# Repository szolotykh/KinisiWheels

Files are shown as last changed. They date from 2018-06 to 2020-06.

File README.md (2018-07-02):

# KinisiWheels
Kinisi wheels are mecanum wheels for DIY projects, designed in mind to be easily made at home or in a small shop without any machinery or sophisticated tools. Wheels parts can be made on any 3D printer without any support material and using only popular types of filament.

## Links
* Facebook: https://www.facebook.com/vsreality
* Instagram: https://www.instagram.com/vsrealityrobotics
* YouTube: https://www.youtube.com/channel/UCnxfsZNEosBJmcfHZYKonFg

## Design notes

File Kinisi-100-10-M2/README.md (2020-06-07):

Kinisi Mecanum Wheels Model 2 (100 mm 10 rollers)
===

Kinisi wheels are mecanum wheels for DIY projects, designed in mind to be easily made at home or in a small shop without any machinery or sophisticated tools. Wheels parts can be made on any 3D printer without any support material and using only popular types of filament.

* Diameter of the wheel: 100mm
* Number of rollers: 10
* Bore diameter: 6mm
* One wheel constructs from 14 printed parts
* Screws assembly

Why this wheels was designe? Main goal is to make low cost and easy to make, available in different sizes and configurations mecanum wheels that can be use in DIY projects.

# Print Settings
* Resolution: Nozzle 0.4 mm, Layer 0.2 mm
* Infill: 30%
* Notes: Rollers should be printed with 50% Infill

# Materials and tools

## Materials
* PLA/ABS Red and Black
* TPU Black
* 3mm Steel Rod (3 feet per wheel) Low-Carbon Steel Rod: https://www.mcmaster.com/#8920K14, Carbon Steel Rod https://www.mcmaster.com/#5544T222
* Locknuts (28 per wheel) https://www.mcmaster.com/#90576A102
* Washers (20 per wheel) https://www.mcmaster.com/#90965A130
* Worm-Drive Clamps https://www.mcmaster.com/#5388K14

## Tools
* 3D Pronter
* Steel Hacksaw
* Die handles
* M3 die
* Thread cutting oil
* 5.5 Wrench
* Pliers
* File set
* Vise

# Filament Cost
| Part | Material | Color | Item weight, g | Amount | Total weight, g | Print time, min |
|---|---|---|---|---|---|---|
| Inner side | PLA | Red | 10.5 | 1 | 10.5 | 81 | 
| Outer side | PLA | Red | 10.5 | 1 | 10.5 | 81 | 
| Roller | TPU | Black | 4.5 | 10 | 45 | 320 | 
| Center | PLA | Red | 15 | 1 | 15 | 128 | 
| Hub | PLA | Black | 2 | 1 | 2 | 20 | 
| Total | | | | 14 | 83 | 10h 30m | 

Total cost of filament: $2.81
PLA $28 for 1kg
TPU $31 for 0.8kg

# Mounting Parts Cost
| Part | Cost | Amount | One wheel cost | 
|---|---|---|---|
| 3mm Steel Rod (3 feet) | 3.67 per three feet | 3 feet | 3.67 | 
| Locknuts | 3.36 per 100 | 28 | 0.94 | 
| Washers | 2.80 per 100 | 20 | 0.56 | 
| Worm-Drive Clamps | 6.02 per 10 | 1 | 0.6 | 
| Total | | | 5.77 | 

# Total cost 
Total cost for 1 wheel is about $8.58

# Roller axis and mounting screws
In order to make roller axis and mounting screws you need to prepare a 3 feet of low-carbon or carbon steel rod (see material section). Then, you should cut the rod on 10 pieces of length 60mm for roller axes, and 4 pieces of length 46 mm for mounting screws using any steel sow. Then, you should make a small chamfer on both ends of each axis and screws. Finally, make 4mm thread on each side of them using M3 die with die holder, remember to apply thread cutting oil before cutting thread.Watch videos below to see how thread cutting and assembling the wheel can be done.

# Videos
* Threading roller axis for Kinisi wheels https://www.youtube.com/watch?v=sRk97DvpTi4
* Assembling Kinisi Mecanum Wheel Model 2 https://www.youtube.com/watch?v=DggJK2FCUzg

# Social:
* Facebook: https://www.facebook.com/vsreality
* Instagram: https://www.instagram.com/vsrealityrobotics
* YouTube: https://www.youtube.com/channel/UCnxfsZNEosBJmcfHZYKonFg

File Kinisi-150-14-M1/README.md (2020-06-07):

Kinisi Mecanum Wheels Model 1 (150 mm 14 rollers)
===
Kinisi wheels is a pair of left and right mecanum wheels. Designed specially to be made on 3D printer with out any support structures.
* Diameter of the wheel: 150mm
* Number of rollers: 14
* Bore diameter: 8mm
* One wheel constructs from 37 printed parts
* Require ServoCity 8mm hub
* Screws assembles

# Print Settings
Rafts:Yes
Supports:No
Resolution: Nozzle 0.4 mm, Layer 0.2 mm
Infill:30%

You can printed all parts from PLA or ABS except roller tires which you should print from TPU other wise you will not be able to put a tire on a roller core.
There some statistic which I collected while 3d print wheels and parts count:

| Part | Material | Color | Item weight, g | Amount | Total weight, g | Time to print, min |  
|---|---|---|---|---|---|---|
| Inside | PLA | Red | 44 | 1 | 44 | 312 | 
| Outside | PLA | Red | 44 | 1 | 44 | 312 | 
| Roller core | PLA | Black | 1.93 | 14 | 27 | 300 | 
| Roller tire | TPU | Black | 6.86 | 14 | 96 | 625 | 
| Central support | PLA | Red | 10 | 1 | 10 | 69 | 
| Secondary beam  | PLA | Black | 3 | 6 | 18 | 136 | 
| Total | | | | 37 | 239 | 29h 14m | 

Total cost of filament: *$6.98*
* PLA $28 for 1kg
* TPU $31 for 0.8kg

Reaf is not require but preferable for roller cores, and  secondary beans.

# Parts (Screws and Nuts)
| Part | Amount | Total cost | McMaster ID |
|---|---|---|---|
| Screw, M4 65 mm | 14 | $3.99 | 91290A083 | 
| Locknut, M4 | 14 | $0.57 | 90576A103 | 
| Scrow, 6-32, 1-3/4 | 10 | $1.42 | 91251A158 | 
| Locknut, 6-32 | 10 | $0.28 | 90631A007 | 
| Total | | $6.26 | | 

Also you need 8mm bore hub from ServoCity
https://www.servocity.com/770-set-screw-hubs#348=105

# Assembling Kinisi Wheel
https://www.youtube.com/watch?v=snKVXKz8MpM

# Social:
* Facebook: https://www.facebook.com/vsreality
* Instagram: https://www.instagram.com/vsrealityrobotics

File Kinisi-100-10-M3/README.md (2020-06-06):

Kinisi Mecanum Wheels Model 3 (100 mm 10 rollers)
===

Kinisi wheels are mecanum wheels for DIY projects, designed in mind to be easily made at home or in a small shop without any machinery or sophisticated tools. Wheels parts can be made on any 3D printer without any support material and using only popular types of filament.

Diameter of the wheel: 100mm
Number of rollers: 10
Bore diameter: 6mm
One wheel constructs from 14 printed parts
Screws assembly
Why this wheels was designe?

Main goal is to make low cost and easy to make, available in different sizes and configurations mecanum wheels that can be use in DIY projects.
Access to the design

If you are interesting to modify design and give me some feedback how to improve it you can download the source from Autodesk gallery: https://gallery.autodesk.com/fusion360/projects/137421/kinisi-mecanum-wheels-model-3-100-mm-10-rollers

# Print Settings
* Rafts: No
* Supports: No
* Resolution: Nozzle 0.4 mm, Layer 0.2 mm
* Infill: 30%
* Notes: Rollers should be printed with 50% Infill

# Materials
* PLA/ABS Red and Black
* TPU Black
* 3mm Steel Rod (3 feet per wheel)
** Low-Carbon Steel Rod https://www.mcmaster.com/#8920K14
** Carbon Steel Rod https://www.mcmaster.com/#5544T222
* Locknuts (12 per wheel) https://www.mcmaster.com/#90576A102
* Washers (20 per wheel) https://www.mcmaster.com/#90965A130
* Worm-Drive Clamps https://www.mcmaster.com/#5388K14

# Tools
* 3D Pronter
* Steel Hacksaw
* Die handles
* M3 die
* Thread cutting oil
* 5.5 Wrench
* Pliers
* File set
* Vise

# Filament Cost
| Part | Material | Color | Item weight, g | Amount | Total weight, g | Print time, min |
|---|---|---|---|---|---|---|
| Inner side | PLA | Red | 11 | 1 | 11 | 91 | 
| Outer side | PLA | Red | 11 | 1 | 11 | 91 | 
| Roller | TPU | Black | 4.5 | 10 | 45 | 320 | 
| Center | PLA | Red | 15 | 1 | 15 | 128 | 
| Hub | PLA | Black | 3 | 1 | 3 | 20 | 
| Total | | | | 14 | 85 | 11h | 

Total cost of filament: $2.86
PLA $28 for 1kg
TPU $31 for 0.8kg

# Mounting Parts Cost
| Part | Cost | Amount | One wheel cost | 
|---|---|---|---|
| 3mm Steel Rod (3 feet) | 3.67 per three feet | 3 feet | 3.67 | 
| Locknuts | 3.36 per 100 | 12 | 0.4 | 
| Washers | 2.80 per 100 | 20 | 0.56 | 
| Worm-Drive Clamps | 6.02 per 10 | 1 | 0.6 | 
| Total | | | 5.23 | 

# Total cost
Total cost for 1 wheel is about $8.09

# Roller axis and mounting screws
In order to make roller axis and mounting screws you need to prepare a 3 feet of low-carbon or carbon steel rod (see material section). Then, you should cut the rod on 10 pieces of length 53.7 mm for roller axes, and 6 pieces of length 46 mm for mounting screws using any steel sow. Then, you should make a small chamfer on both ends of each axis and screws. Finally, make 4mm thread on each side of 46 mm rods using M3 die with die holder, remember to apply thread cutting oil before cutting thread. Watch videos below to see how thread cutting and assembling the wheel can be done.

# Assembling Kinisi Wheel Model 3
https://www.youtube.com/watch?v=xH2ZxzZyMjw

# Social
* Facebook: https://www.facebook.com/vsreality
* Instagram: https://www.instagram.com/vsrealityrobotics
* YouTube: https://www.youtube.com/channel/UCnxfsZNEosBJmcfHZYKonFg
* Autodesk: https://gallery.autodesk.com/fusion360/users/5C4LRV5ULQZH

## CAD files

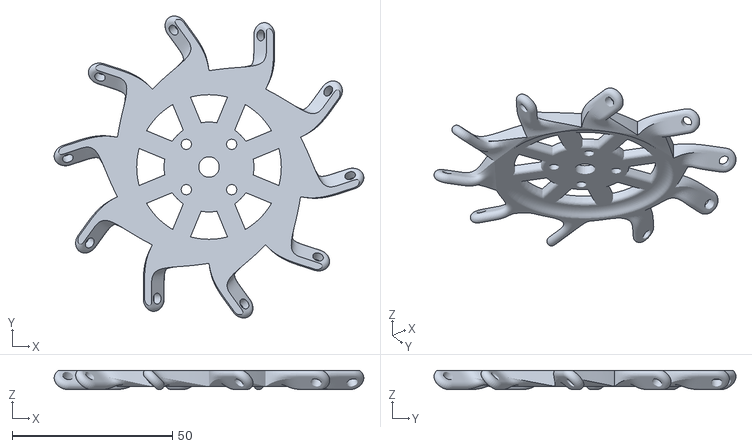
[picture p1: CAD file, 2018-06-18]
Kinisi-100-10-M2/Left outer side.stl
96.5 x 94.1 x 6.04

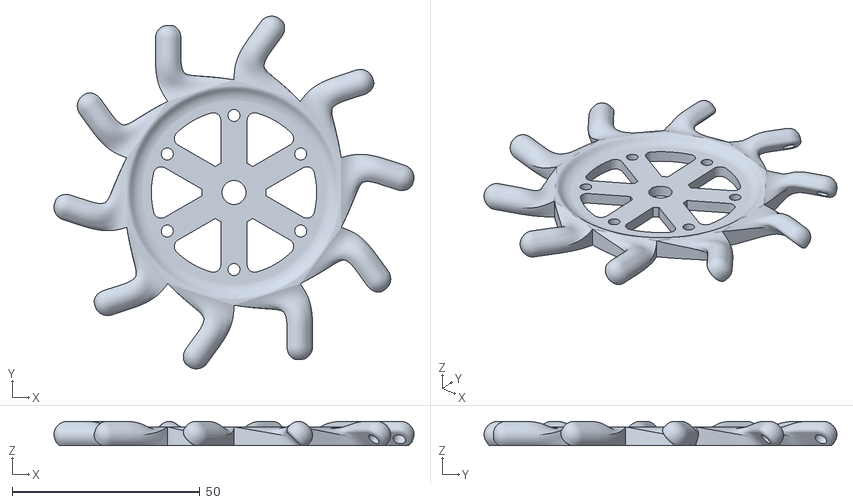
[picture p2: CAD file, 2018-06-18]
Kinisi-100-10-M3/Left inner side.stl
95.8 x 93.9 x 6.47

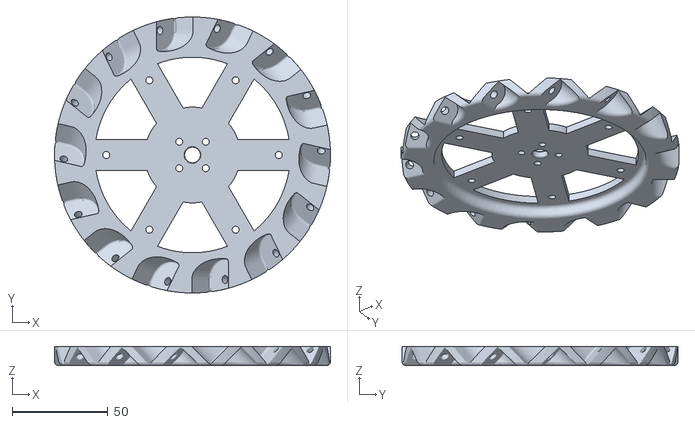
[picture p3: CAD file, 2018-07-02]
Kinisi-150-14-M1/Inside right.stl
144.0 x 144.0 x 10.0

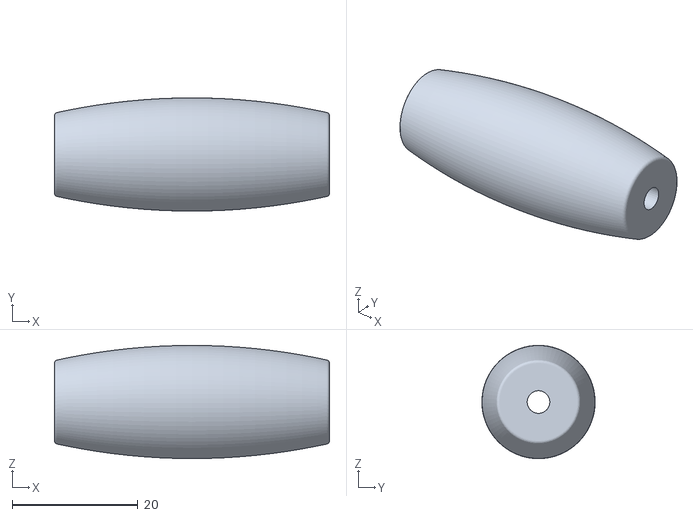
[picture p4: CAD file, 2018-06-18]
Kinisi-100-10-M2/Roller.stl
43.7 x 18.0 x 18.0

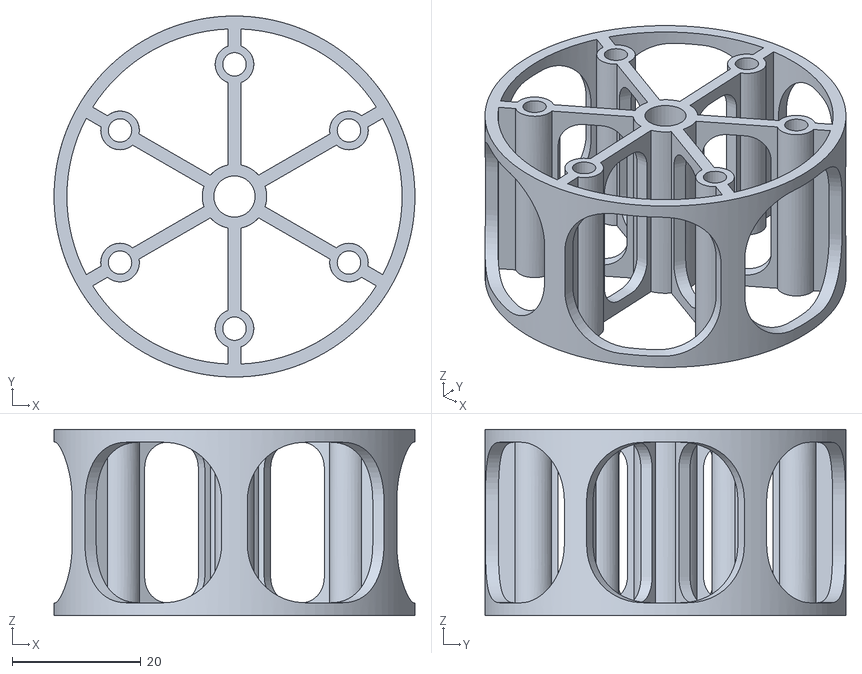
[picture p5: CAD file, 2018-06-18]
Kinisi-100-10-M3/Center.stl
56.0 x 56.0 x 28.9

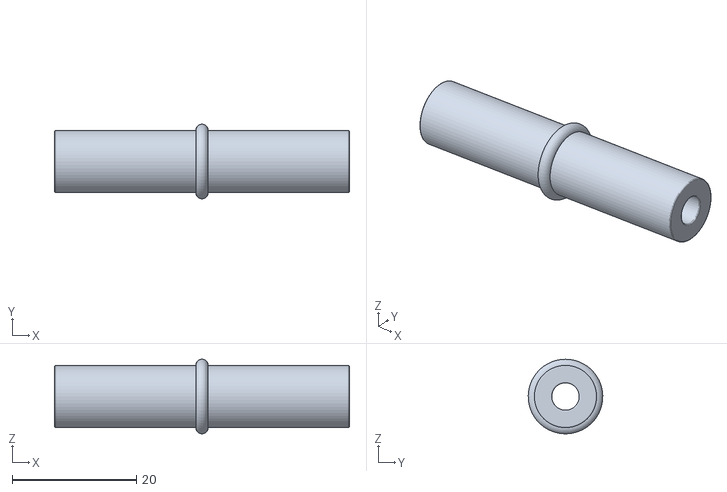
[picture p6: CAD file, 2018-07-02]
Kinisi-150-14-M1/Roller core.stl
47.4 x 12.0 x 12.0

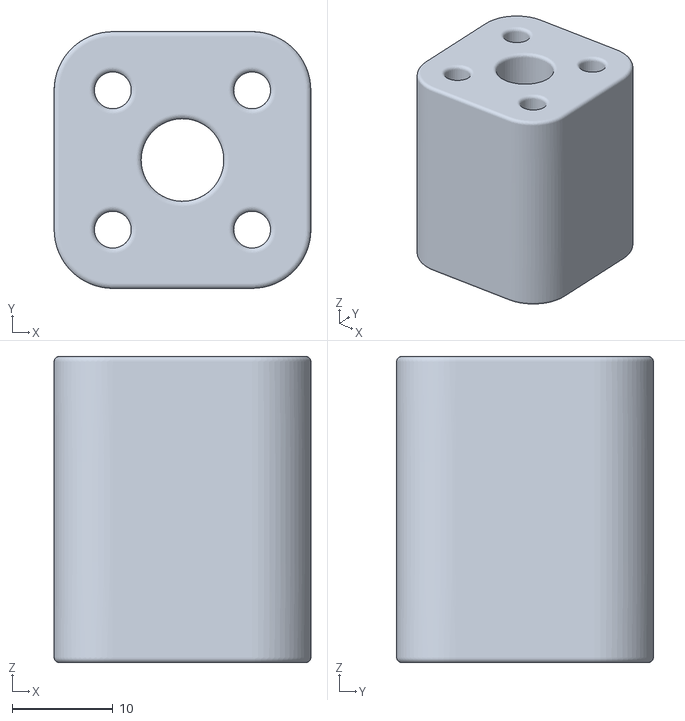
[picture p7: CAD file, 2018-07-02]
Kinisi-150-14-M1/Central support.stl
25.5 x 25.5 x 30.4

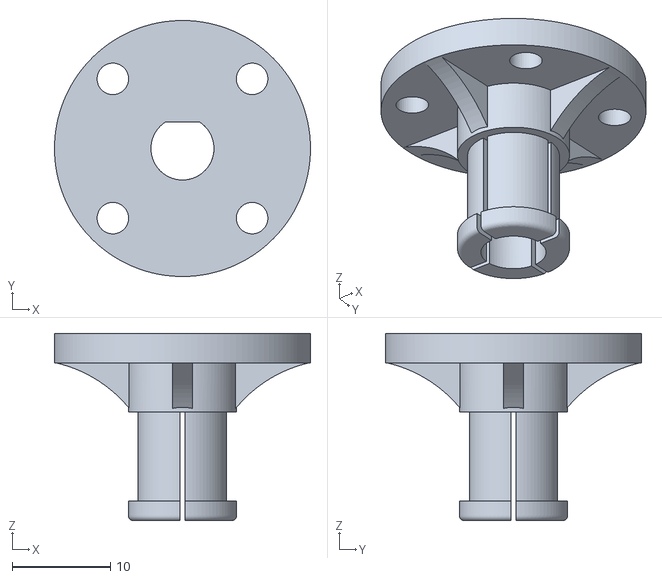
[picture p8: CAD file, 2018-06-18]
Kinisi-100-10-M2/Hub for motor.stl
26.0 x 26.0 x 19.0

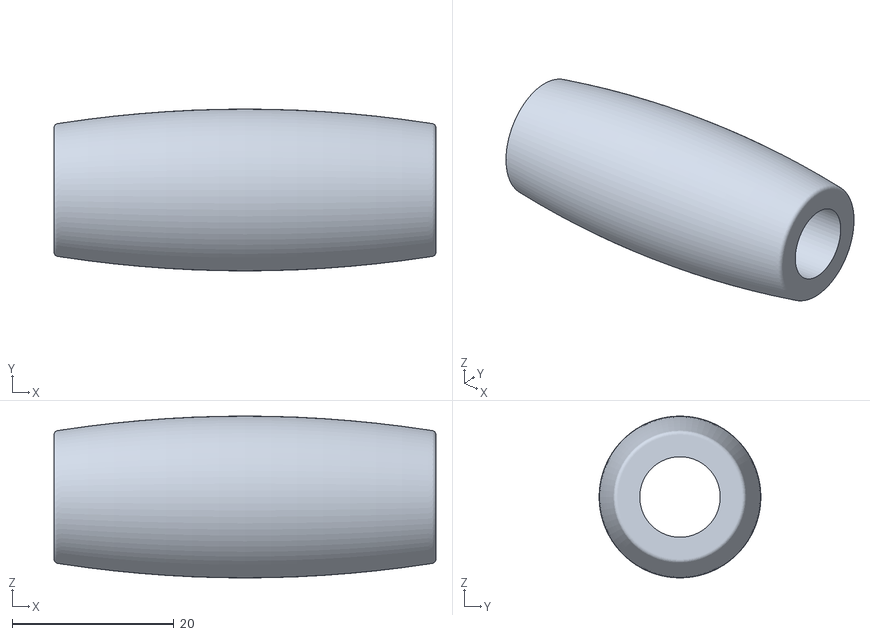
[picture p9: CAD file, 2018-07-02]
Kinisi-150-14-M1/Roller tire.stl
47.2 x 20.0 x 20.0

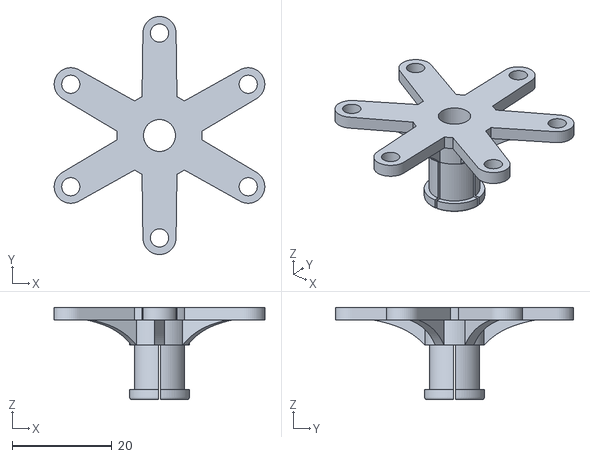
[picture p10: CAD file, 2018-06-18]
Kinisi-100-10-M3/Hub.stl
42.1 x 47.6 x 18.5

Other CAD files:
Kinisi-100-10-M2/Right outer side.stl
Kinisi-100-10-M3/Right outer side.stl
Kinisi-150-14-M1/Outside left.stl
Kinisi-100-10-M2/Right inner side.stl
Kinisi-100-10-M3/Left outer side.stl
Kinisi-100-10-M3/Right inner side.stl
Kinisi-100-10-M2/Left inner side.stl
Kinisi-150-14-M1/Outside right.stl
Kinisi-100-10-M2/Center.stl
Kinisi-100-10-M2/Hub.stl
Kinisi-100-10-M3/Roller.stl
Kinisi-150-14-M1/Inside left.stl
Kinisi-150-14-M1/Secondary beam.stl

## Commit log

2018-06-18 Added files for Kinisi-100-10
    [Center.stl, Hub for motor.stl, Hub.stl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]
2018-06-18 Added files for Kinisi-100-10-M
    [Center.stl, Hub.stl, Left inner side.stl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]
2018-07-02 Renamed wheels folders. Added STL files for Kinisi-150-14-M1.
    [Center.stl, Central support.stl, Hub for motor.stl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]
